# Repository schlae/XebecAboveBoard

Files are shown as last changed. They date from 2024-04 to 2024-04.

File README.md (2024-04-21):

# Xebec/Intel Above Board Clone

The Above Board is a memory card for the IBM PC/XT series. It uses an 8-bit ISA
bus connector to provide both extended (XMS) and expanded (EMS) memory. This
design is a copy of Xebec's copy of Intel's original design.

The card supports either 64Kbit or 256Kbit DRAM chips. The mix of XMS/EMS is
configured using the switch bank in the upper right corner.

SW1: Off for 64K, On for 256K DRAM chips
SW2-4: XMS selection. Set according to the amount of memory on your motherboard

| SW2 | SW3 | SW4 | Motherboard RAM |
|-----|-----|-----|---|
| Off | On  | On  | 256KB |
| Off | On  | Off | 320KB |
| Off | Off | On  | 384KB |
| Off | Off | Off | 448KB |
| On  | On  | On  | 512KB |
| On  | On  | Off | 576KB |
| On  | Off | On  | 640KB (No XMS installed) |

SW5-8: Base IO address for page control registers, etc

| SW5 | SW6 | SW7 | SW8 | Address |
|-----|-----|-----|-----|---|
| On | On | On | On | 0x208 |
| On | On | On | Off | 0x218 |
| On | Off | On | Off | 0x258 |
| On | Off | Off | On | 0x268 |
| Off | On | Off | On | 0x2A8 |
| Off | On | On | Off | 0x2B8 |
| Off | Off | Off | On | 0x2E8 |

The design files are for educational purposes. The board has not been cleaned
up for fabrication and still has a number of DRC errors. A practical modern
XMS/EMS board would use modern SRAM chips instead of a large number of old
and unreliable DRAM chips. This would also obviate the need for the vintage
delay line device that is used to generate the RAS/CAS timing pulses.

There is a single PROM on the board (an 82S131). The contents of it are in
XEBEC1.BIN.

## License

This work is licensed under a Creative Commons Attribution-ShareAlike 4.0
International License. See [https://creativecommons.org/licenses/by-sa/4.0/](https://creativecommons.org/licenses/by-sa/4.0/).

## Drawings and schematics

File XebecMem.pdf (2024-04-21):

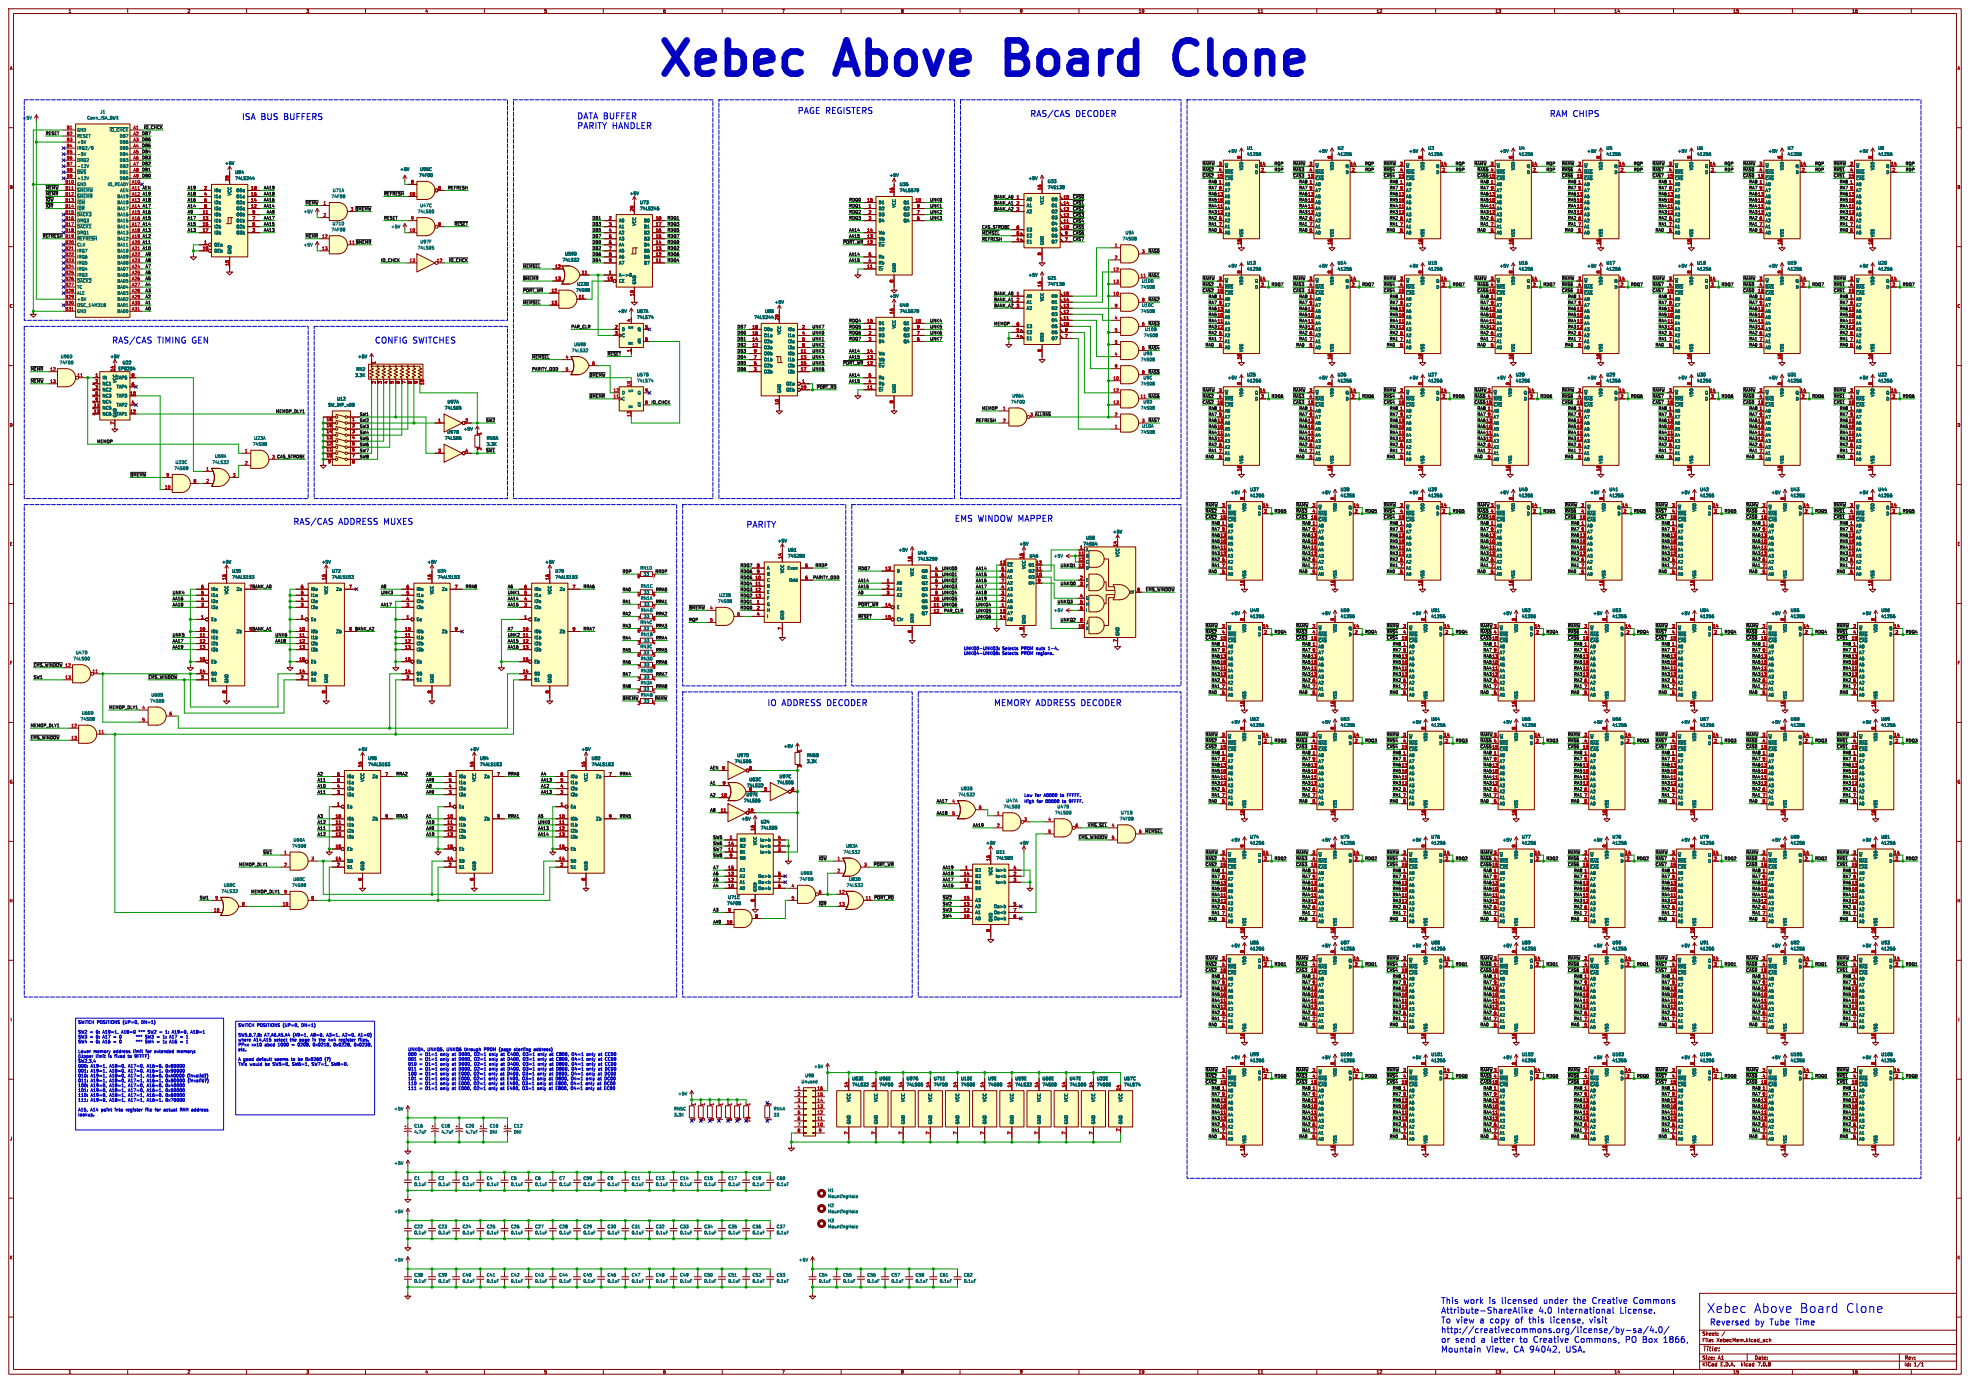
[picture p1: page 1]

IO_READY A10 AEN A11 BA19 A12 BA18 A13 BA17 A14 BA16 A15 BA15 A16 BA14 A17 BA13 A18 BA12 A19 DB7 A2 BA11 A20 BA10 A21 BA09 A22 BA08 A23 BA07 A24 BA06 A25 BA05 A26 BA04 A27 BA03 A28 BA02 A29 DB6 A3 BA01 A30 BA00 A31 DB5 A4 DB4 A5 DB3 A6 DB2 A7 DB1 A8 DB0 A9 GND B1 GND B10 ~{SMEMW} B11 ~{SMEMR} B12 ~{IOW} B13 ~{IOR} B14 ~{DACK3} B15 DRQ3 B16 ~{DACK1} B17 DRQ1 B18 ~{REFRESH} B19 RESET B2 CLK B20
IRQ3 B25 ~{DACK2} B26 TC B27 ALE B28 +5V B29 +5V B3 OSC_14M318 B30 GND B31
IRQ2/9 B4
-5V B5 DRQ2 B6

Xebec Above Board Clone

RAS/CAS TIMING GEN
+5V U22 EP8204 VCC 14 GND

High for 00000 to 9FFFF. EMS WINDOW MAPPER

~{RAS0} RA8 RA6 A11
RAS/CAS ADDRESS MUXES

Low for A0000 to FFFFF. PARITY

Lower memory address limit for extended memory: (Upper limit is fixed to 9FFFF) SW2,3,4

001 = O1=1 only at D000, O2=1 only at D400, O3=1 only at C800, O4=1 only at CC00
010 = O1=1 only at D000, O2=1 only at D400, O3=1 only at D800, O4=1 only at CC00
011 = O1=1 only at D000, O2=1 only at D400, O3=1 only at D800, O4=1 only at DC00
100 = O1=1 only at E000, O2=1 only at D400, O3=1 only at D800, O4=1 only at DC00
101 = O1=1 only at E000, O2=1 only at E400, O3=1 only at D800, O4=1 only at DC00

110 = O1=1 only at E000, O2=1 only at E400, O3=1 only at E800, O4=1 only at DC00
111 = O1=1 only at E000, O2=1 only at E400, O3=1 only at E800, O4=1 only at EC00

This work is licensed under the Creative Commons
To view a copy of this license, visit
http://creativecommons.org/license/by-sa/4.0/
or send a letter to Creative Commons, PO Box 1866,
Mountain View, CA 94042, USA.

Reversed by Tube Time

Id: 1/1 Title: File: XebecMem.kicad_sch Sheet: /
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
